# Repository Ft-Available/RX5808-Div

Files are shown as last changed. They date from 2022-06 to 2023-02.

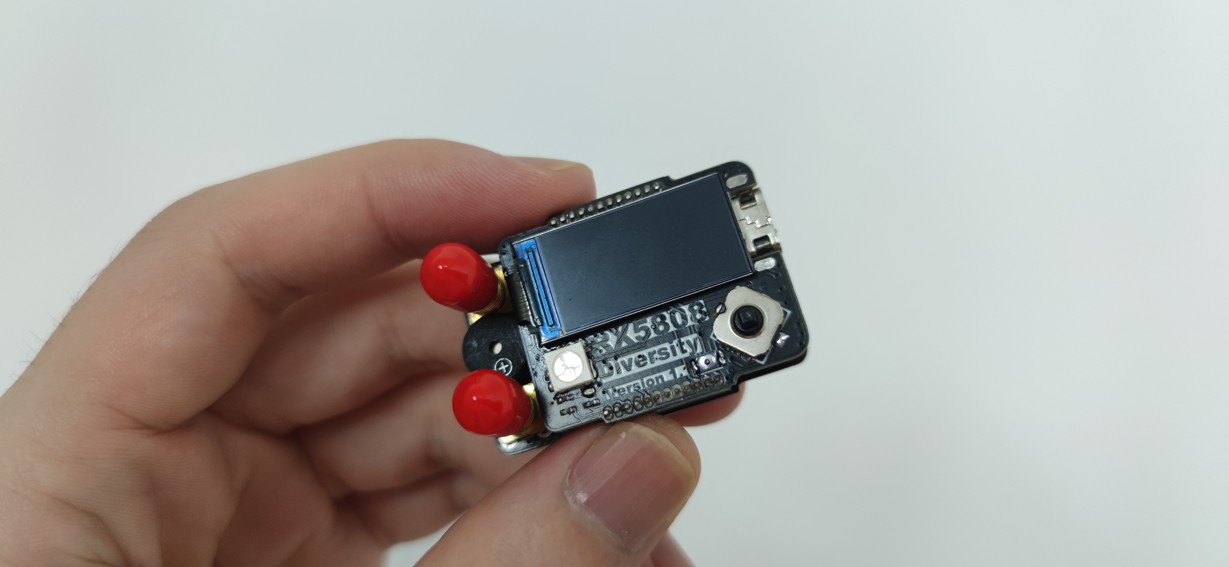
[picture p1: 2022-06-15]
Img/img3.jpg

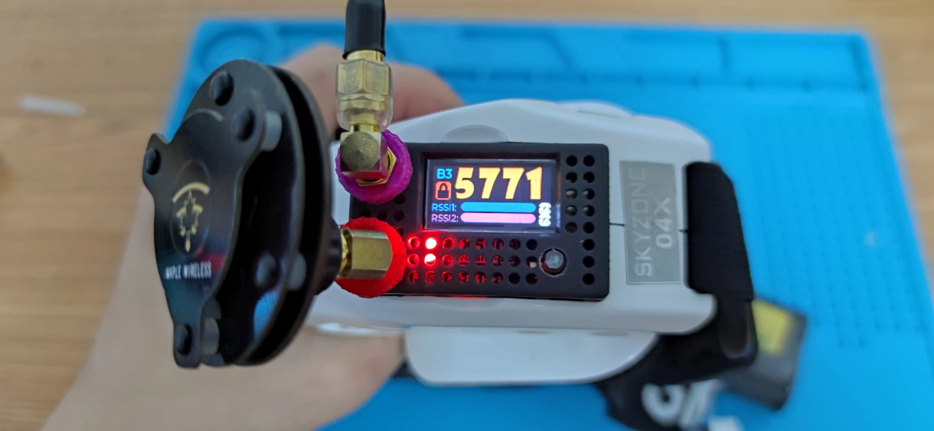
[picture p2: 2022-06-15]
Img/Skyzone_04x.jpg

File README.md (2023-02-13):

# RX5808-Div
## 1.界面设计基于LVGL

演示视频见：https://www.bilibili.com/video/BV1yr4y1371b

ui

1)主界面长按确定键，可锁定/解锁手动频道,短按进入菜单；  解锁情况下，按上下左右可调整频率。

2)菜单界面分为三块内容：扫描；设置；关于。

 按上下切换菜单选项，确定进入子菜单，左键返回主界面

3）扫描菜单有三个子内容：

图扫描显示频率5300-5900MHz信号强度；

表扫描显示将图传频道信号强度按不同颜色显示，扫描结束，频率切换至最当前信号强度最好的频道，并显示在右上角。

RSSI校准用于校准RSSI,未开启图传会校准失败，成功则会保存结果。

4）设置界面可设置显示屏背光强度，风扇转速、开机动画、蜂鸣器等是否开启，OSD制式需要保存后重新在主页面开启才能生效。

5）关于界面显示相关信息。

## 2.OSD支持

OSD功能由林面包（B站ID）添加，非叠加模式，主界面下解锁即可开启。

演示视频见：[https://www.bilibili.com/video/BV1ya411g78U ](https://www.bilibili.com/video/BV1ya411g78U) 与接收机UI完全同步。

osd

## 3.硬件设计

硬件开源地址：https://oshwhub.com/ftps/rx5808-div

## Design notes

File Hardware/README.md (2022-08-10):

# RX5808-Div-Hardware
Top 文件夹下为控制电路硬件源工程（AD）

-----ESP32         （ESP32版本带串口和USB）

    

-----ESP32_Model         （ESP32模组版本  无串口和USB）

    

因个人时间原因，交由网友打样，暂未发现问题，固件和ESP32版本不一致，详细请看TOOl文件夹下说明

-----STM32         （SMT32版本）

   

BUT 文件夹下为双RX5808接收电路硬件源工程（AD）



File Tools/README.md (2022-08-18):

# RX5808-Div-Tool

RX5808下载固件指南

一、	STM32版本

STM32固件为STM32_Firmware.zip，STM32可用USB，UART，SWD下载，不再赘述。

二、	ESP32版本

1、解压此目录下ESP32_FirmWare.zip文件夹，得到三个xxx.bin文件，如下图：



2、解压此目录下flash_download_tool_3.9.2_0.zip文件夹，得到以下文件：


 
3、双击flash_download_tool_3.9.2_0.exe打开下载程序：



选择ESP32并点击OK。

4.将解压得到的bin文件按下图顺序打开：

         bootloader.bin     0x1000
         
         partition-table.bin  0x8000
         
         RX5808.bin        0x10000 
         
 

5.SPIFLASH按下图设置：


 
6.选择COM口并下载：（下图是下载完成的样子）
 


7.问题
如遇花屏问题用ESP32_FirmWare_Slow固件。

2022.8.10新增模组版固件为ESP32_Model_FirmWare。

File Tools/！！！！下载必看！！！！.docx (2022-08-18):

RX5808下载固件指南

给我小板凳儿

1、 STM32版本

STM32固件为STM32_Firmware.zip

STM32可用USB，UART，SWD下载，不再赘述。

2、 ESP32版本

1、解压此目录下ESP32_FirmWare.zip文件夹，得到三个xxx.bin文件，如下图：

2、解压此目录下flash_download_tool_3.9.2_0.zip文件夹，得到以下文件：

3、双击flash_download_tool_3.9.2_0.exe打开下载程序：

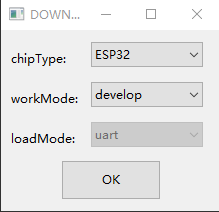
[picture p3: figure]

选择ESP32并点击OK。

4.将解压得到的bin文件按下图顺序打开：

bootloader.bin 0x1000

partition-table.bin 0x8000

RX5808.bin 0x10000

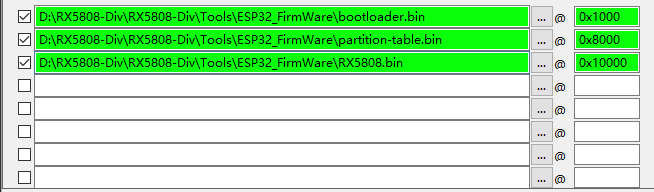
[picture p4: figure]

5.SPIFLASH按下图设置：

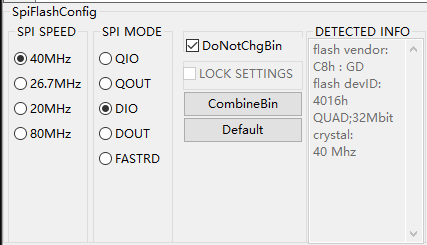
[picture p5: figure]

6.选择COM口并下载：（下图是下载完成的样子）

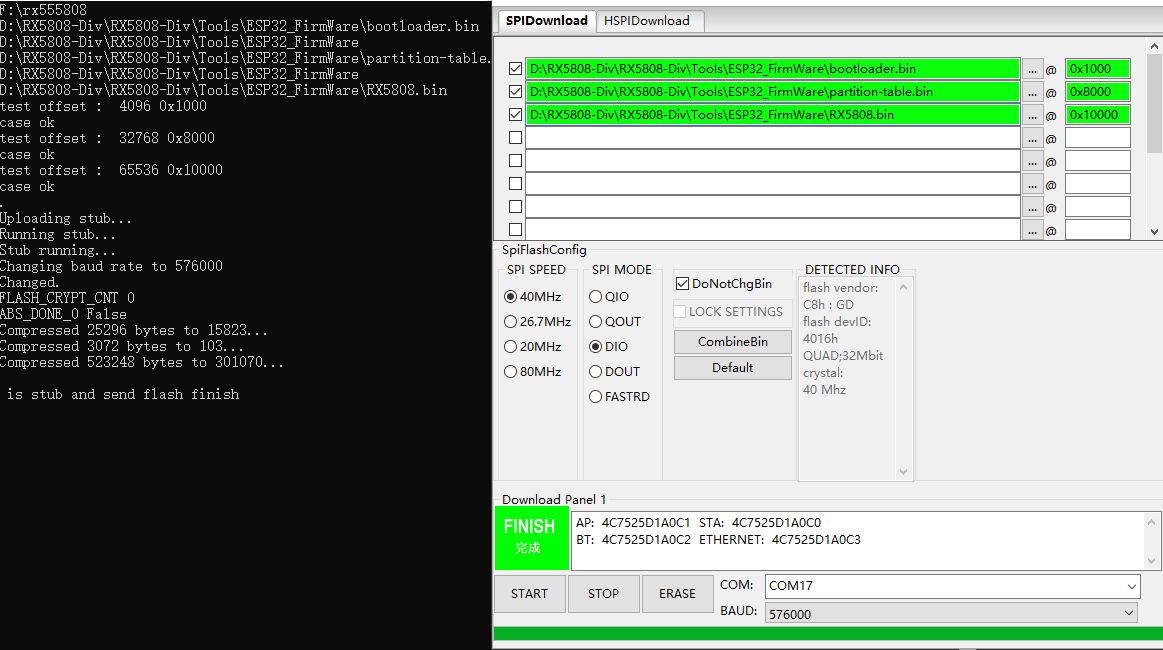
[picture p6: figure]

7.问题

如遇花屏问题用ESP32_FirmWare_Slow固件。

模组版固件为ESP32_Model_FirmWare。

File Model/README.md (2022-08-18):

# RX5808-Div-Model

Skyzone_04x文件夹下适用于Skyzone_04系列眼镜：

提供源文件和打印文件，大家可自行更改

Skyzone_04x_Model

Fatshark_Hdo文件夹下模型由网友(B站 DP团队)贡献：

材料 ：光固化和尼龙烧结（耐温高于65度）， PLA PETG 等材料都可以

FDM打印机在打印过程中不需要开启支撑，层高0.1 ，喷嘴直径不能大于0.4mm

风扇版本为1504 风扇

 



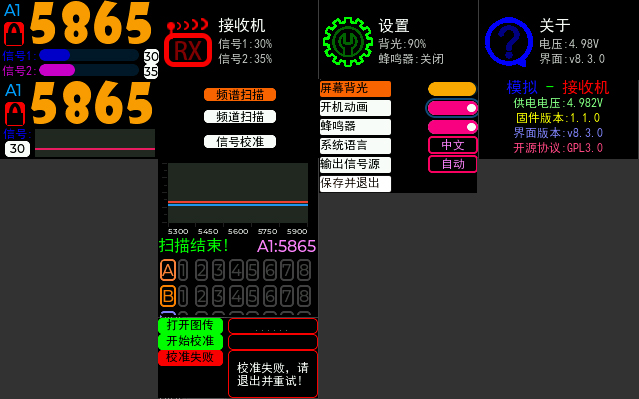
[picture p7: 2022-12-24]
Img/ui.jpeg

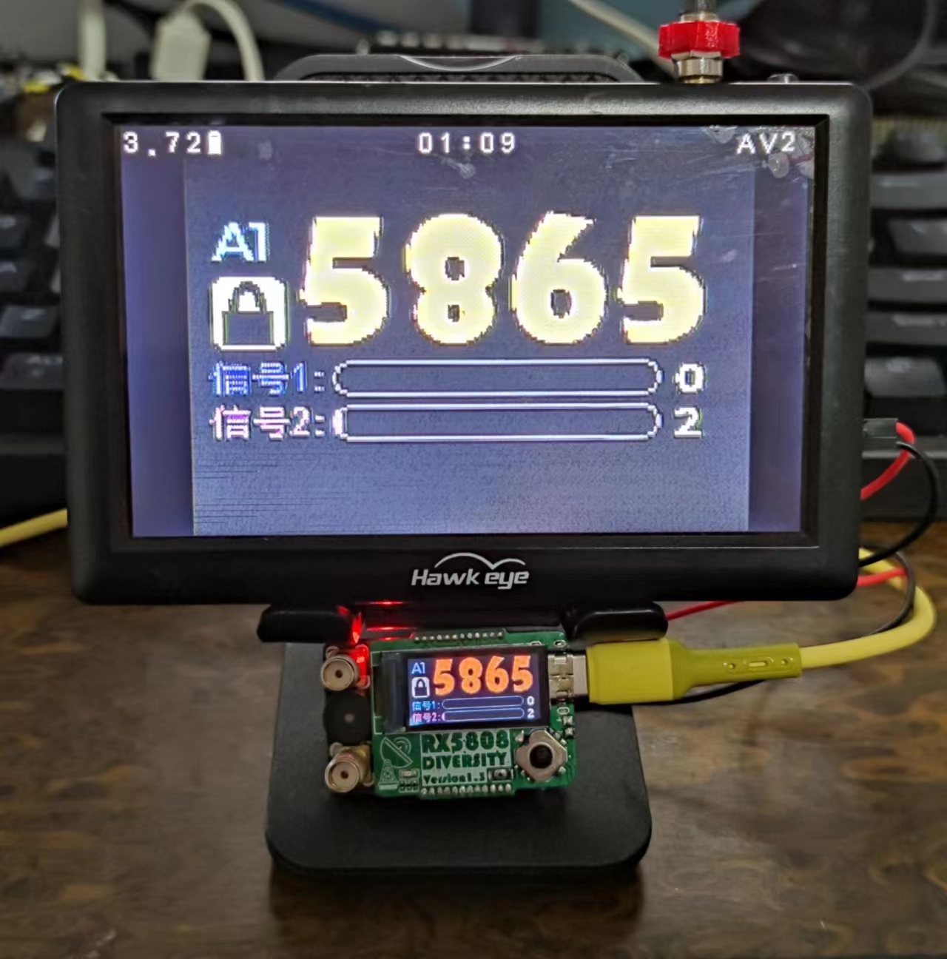
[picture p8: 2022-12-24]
Img/osd.jpeg

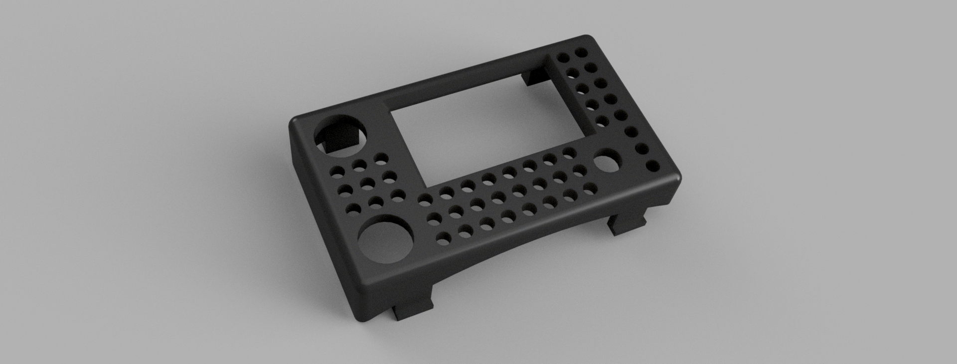
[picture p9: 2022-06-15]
Img/Skyzone_04x_Model.png

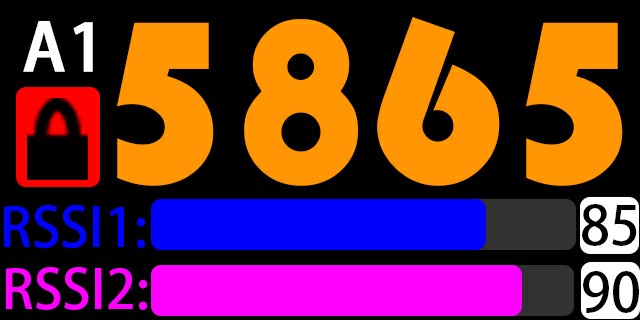
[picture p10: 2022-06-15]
Resources/main.jpg

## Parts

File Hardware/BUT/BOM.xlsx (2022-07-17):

Comment | Description | Designator | Footprint | LibRef | Quantity
BELL | 有源蜂鸣器 | BEEP1 | BEEP 5x9x5.5 | Beep | 1
RX5808 | SPI控制RX5808 | CM1, CM2 | COMM-SMD_12P_RX5808 | RX5808 | 2
LED | LED | DS1 | 0402_LED | LED | 1
Header 9 | Header, 9-Pin | P1 | HDR-1X9 | Header 9 | 1
Header 12 | Header, 12-Pin | P2, P3 | HDR1.27-1x12-M | Header 12 | 2
SS8050 | NPN三极管 | Q1 | SOT23A | SS8050 | 1
1K | 电阻 | R1, R3 | 0402_RES | RES | 2
10K | 电阻 | R2 | 0402_RES | RES | 1
SMA-KE901 | >17mm天线座 | RF1, RF2 | SMA-TH_SMA-KE901 | SMA-KE901 | 2

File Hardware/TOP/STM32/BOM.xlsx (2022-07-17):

Comment | Description | Designator | Footprint | LibRef | Quantity
100nf | 无极性电容 | C1, C4, C5, C6, C7, C8, C9, C10, C11, C12, C13, C14, C15, C16, C17 | 0402_CAP | Cap | 15
47uf | 极性电解电容 | C2 | CAP-3216 | Cap Pol | 1
10uf | 无极性电容 | C3 | 1206_CAP | Cap | 1
RGB LED | 无极性电容 | D1 | LED-SMD_6P-L5.0-W5.0-TL | WS2812 | 1
LED | LED | DS1 | 0402_LED | LED | 1
USB type C | TYPEC接口-16PIN | J1 | USB-C-SMD_TYPE-C-16M-005 | Type-C | 1
2.2uH | 电感 | L1 | L 1206 | Inductance | 1
Header 12 | 排针 | P1, P2 | HDR1.27-1x12 | Header 12 | 2
SS8050 | NPN三极管 | Q1 | SOT23A | SS8050 | 1
100K | 电阻 | R1 | 0402_RES | RES | 1
22K | 电阻 | R2, R6 | 0402_RES | RES | 2
22R | 电阻 | R3, R4 | 0402_RES | RES | 2
1M | 电阻 | R5, R7 | 0402_RES | RES | 2
10R | 电阻 | R8 | 0402_RES | RES | 1
1K | 电阻 | R9, R15 | 0402_RES | RES | 2
10K | 电阻 | R10, R11, R12, R13, R14, R16, R17 | 0402_RES | RES | 7
薄膜按键 | 薄膜按键 | REST1 | SW-SMD_ST-1195 | Jumper | 1
7*7*5-6P WX | 五向按键 | SW1 | SW-SMD_8P-L7.0-W7.0-P1.40-LS7.4-TL | 7*7*5-6P WX | 1
IPS0.96_80x160 | IPS-80x160 | TFT1 | IPS-0.96 | IPS0.96_80x160 | 1
SY8079AAC | DCDC电源 | U1 | SOT-23-5_L3.0-W1.7-P0.95-LS2.8-TL | SY8079AAC | 1
74LVC4066PW | 模拟开关 | U2 | SSOP-14_L6.5-W5.2-P0.65-LS8.0-BL | 74LVC4066PW | 1
STM32F411CEU6 | STM32单片机 | U3 | UFQFPN-48_L7.0-W7.0-P0.50-BL-EP | STM32F411CEU6 | 1
ZD24C64A-XGMT | E2PROM | U4 | TSSOP-8_L4.4-W3.0-P0.65-LS6.4-BL-2 | ZD24C64A-XGMT | 1
8M | 晶振 | Y1 | CSTCE8M00G55 | XTAL_1 | 1

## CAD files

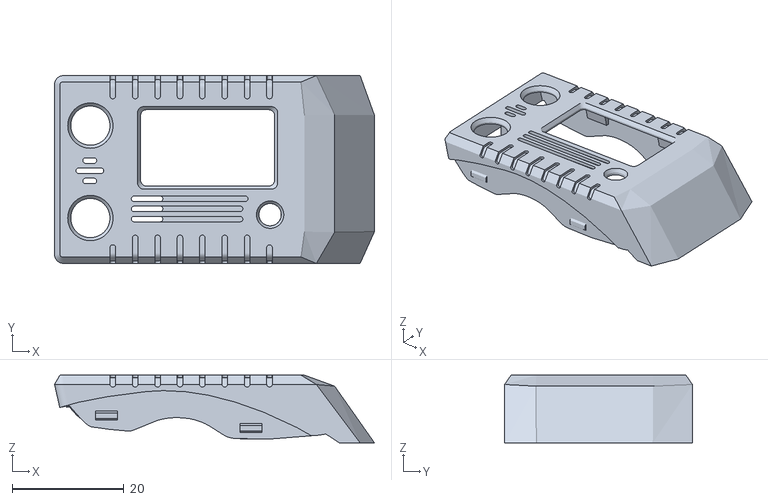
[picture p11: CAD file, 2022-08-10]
Model/Fatshark_Hdo/FatShark5808.stl
57.2 x 33.6 x 12.1

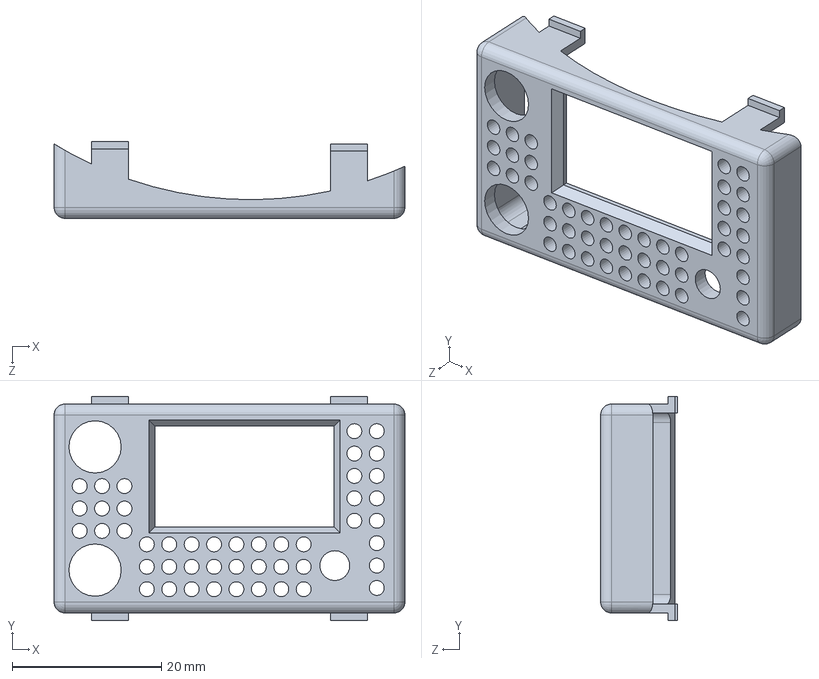
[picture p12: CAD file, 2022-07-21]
Model/Skyzone_04x/Skyzone_04x.SLDPRT
47.0 x 30.0 x 10.3 mm

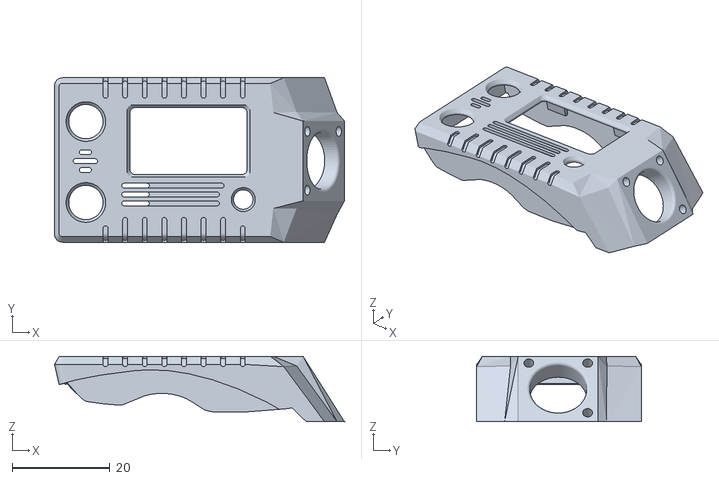
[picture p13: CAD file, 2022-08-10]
Model/Fatshark_Hdo/FatShark5808_1504.stl
59.2 x 33.6 x 13.4

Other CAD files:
Model/Skyzone_04x/Skyzone_04x.STL

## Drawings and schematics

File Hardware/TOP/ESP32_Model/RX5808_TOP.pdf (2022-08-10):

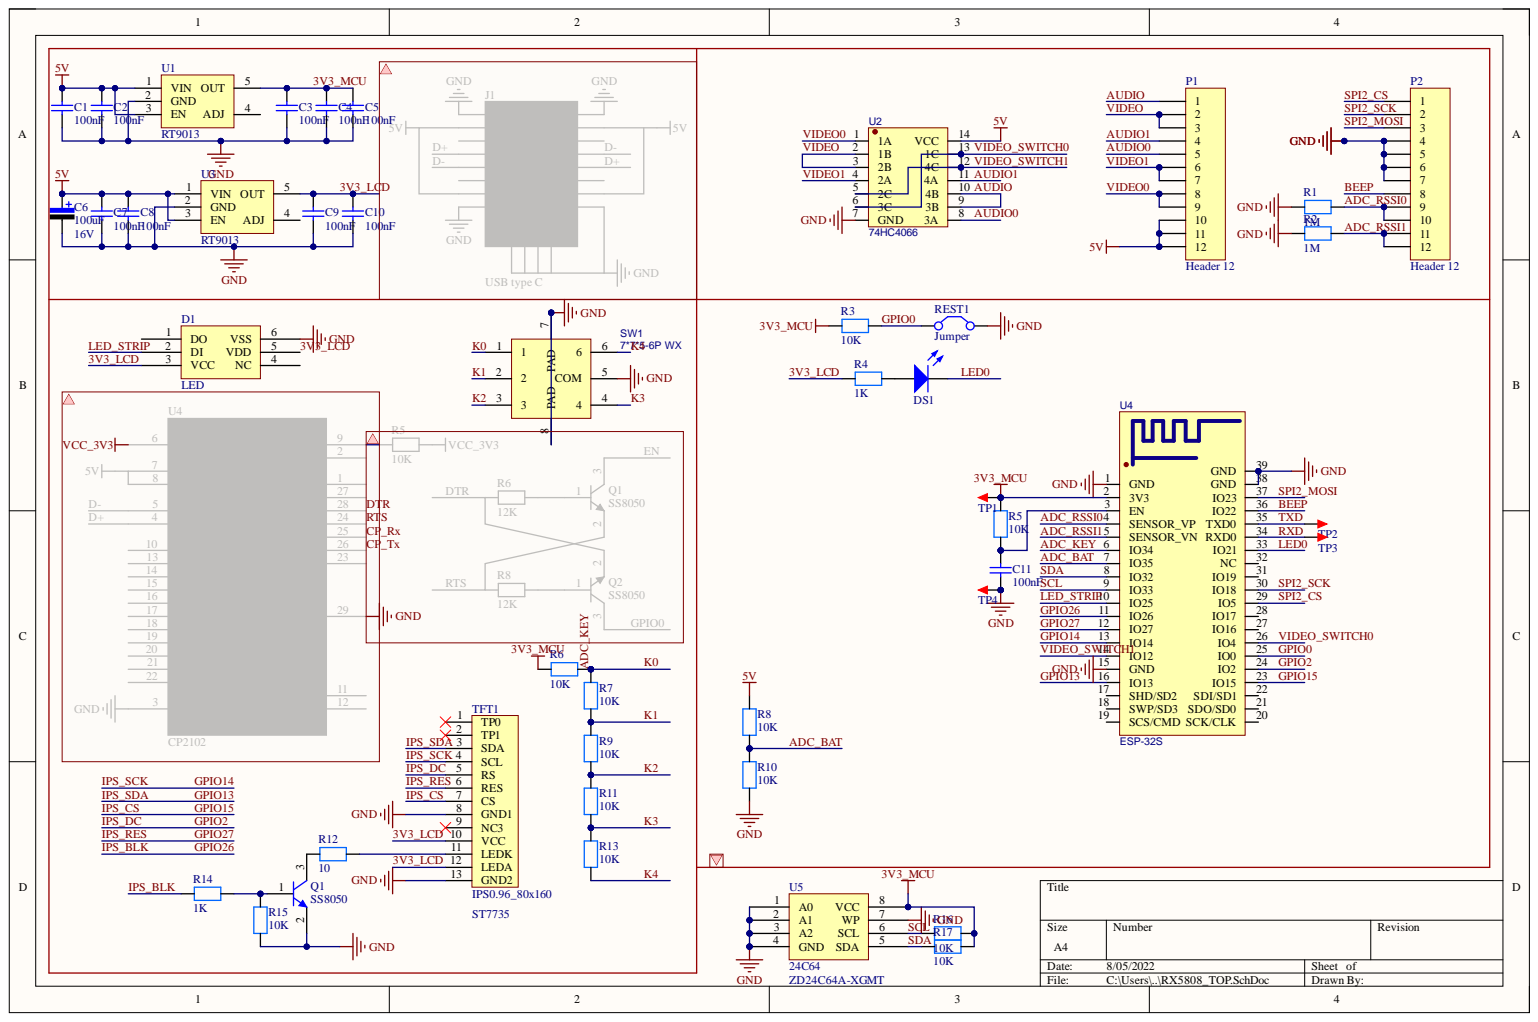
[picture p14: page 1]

GND 4 | SDA

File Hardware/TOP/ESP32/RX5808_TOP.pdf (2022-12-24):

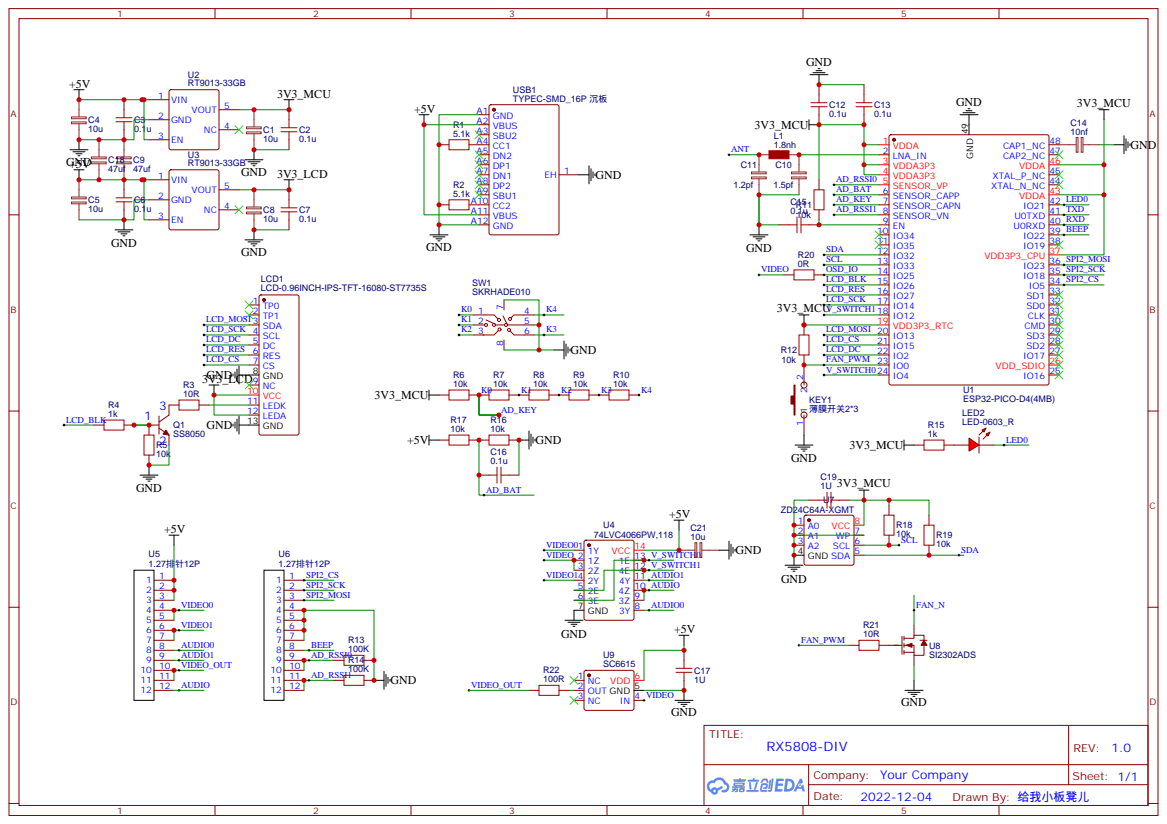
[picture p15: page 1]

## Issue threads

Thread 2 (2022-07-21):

Shell model for fatshark HDO

luttesudo, 2022-07-21:
Do you have a case model for the fatshark HDO? Or is there a modifiable file for O4X?

Ft-Available, 2022-07-21:
I don't have fat shark glasses, so I didn't design the 3D model, now I have uploaded the 04X modifiable model, which was designed with SolidWords.

luttesudo, 2022-07-21:
Thank you for the upload, I will share the model after I revise it, it may be later, I am more busy

Closed 2023-09-29.

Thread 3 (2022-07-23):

看到esp32修改了几个电容，请问这个改动的是否重要

Mason-star, 2022-07-23:

Ft-Available, 2022-07-23:
不知道你说的是哪几个电容，和esp相连的C11 10nf不可更改更不可缺少，其次esp32 天线Π型电路的电容和电感不可更改，其余电容大都为滤波作用，可以适当更改和替换。

Mason-star, 2022-07-23:
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

之前一个版本，bom表除了c11以外都为100nf，这两天，仔细看了一下原理图，发现c15和c16是1.2pf和1.5pf，c10为100nf和bom表有些出入，是pcb改动导致的bom表变动，还是bom表有误？

Ft-Available, 2022-07-23:
BOM表有误，已修改并上传，主要参考原理图

Closed 2022-07-23.

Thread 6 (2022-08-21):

OSD支持 - OSD Support Request

ChisBread, 2022-08-21:
hello, 这里是刚接触嵌入式几天的新手(计算机专业,目前是后端开发)，说的不对还请多多包涵

**功能描述:**
参考RF接收机提供的使用接收屏调参的OSD功能，在调整频段时无需摘下眼镜
**ESP32 A/V输出:**
我研究了一下esp32通过DAC实现A/V输出的可行性，似乎效果相当不错
《ESP32 Composite Video(ESP32 合成视频)》
https://www.youtube.com/watch?v=5t1_XNc3vNw
https://www.bilibili.com/video/BV12V411o7xW
**改造项目的可能性:**
TOP:
我阅读了固件代码和原理图，DAC引脚目前被IPS_BLK和LED_STRIP占用了，可能需要另想办法。不清楚74HC4066是否能加一路video输入，按我的理解应该是不够用了（4路的输入被a0,a1,v0,v1占了, 如果用6路的开关也许可以实现这个功能?)
BUT:
好像不需要做什么改动

最后感谢作者的开源，让我有一个非常有趣的入门体验！没有什么比学习新东西更快乐的了 :D

ChisBread, 2022-08-22:
Supports [LVGL](https://lvgl.io/) graphics library
https://github.com/aquaticus/esp32_composite_video_lib

ChisBread, 2022-08-29:
https://github.com/ChisBread/RX5808-Div/tree/composite_video
我自己写了
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

Ft-Available, 2022-08-29:
这个很有意思，你已经实现了，(●'◡'●)。

ChisBread, 2022-08-29:
是啊，不知道你在不在蛋总（独自飞舞）的群里
我写好固件，修改了原理图（去掉了RGB，加上了双刀单掷模拟开关），蛋总帮我修改了PCB然后去打样了
长按解锁后，VIDEO切换到DAC_VIDEO，这样眼镜里就能看到OSD UI
因为和主线代码相差比较多，硬件也不一样，所以单开了分支，希望之后这个功能可以合并到主线

caixiaohai0, 2022-08-29:
> 是啊，不知道你在不在蛋总（独自飞舞）的群里 我写好固件，修改了原理图（去掉了RGB，加上了双刀单掷模拟开关），蛋总帮我修改了PCB然后去打样了 长按解锁后，VIDEO切换到DAC_VIDEO，这样眼镜里就能看到OSD UI 因为和主线代码相差比较多，硬件也不一样，所以单开了分支，希望之后这个功能可以合并到主线

大佬，可以上传原理图到你的分支里？

ChisBread, 2022-08-29:
> > 是啊，不知道你在不在蛋总（独自飞舞）的群里 我写好固件，修改了原理图（去掉了RGB，加上了双刀单掷模拟开关），蛋总帮我修改了PCB然后去打样了 长按解锁后，VIDEO切换到DAC_VIDEO，这样眼镜里就能看到OSD UI 因为和主线代码相差比较多，硬件也不一样，所以单开了分支，希望之后这个功能可以合并到主线
>
> 大佬，可以上传原理图到你的分支里？

我用macOS不能直接修改作者的工程文件（需要转成其它格式），所以没办法可协作地改动repo里的原理图
出于可维护性考虑，这部分的希望还是作者来统一修改
这是我的原理图，圈起来的是修改的部分(待勘误)，如果作者同步完，验证无误的话。可以在我的[composite_video](https://github.com/ChisBread/RX5808-Div/tree/composite_video)分支合并后提交到主线。
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

这个DAC VIDEO也许不仅可以作为OSD，别的玩法可以在合并后研究研究

ChisBread, 2022-08-29:
video功能合并前，先打开这个issue吧

ChisBread, 2022-08-29:
这个原理图图中有一处不规范，type-c的CC1 CC2应该分别接下拉电阻

caixiaohai0, 2022-08-30:
大佬，你原理图部分是按照那个模块或芯片画的，我对比了一下esp32 wroom-32d这个模块的原理图发现闪存这部分IO和你的不一样
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

caixiaohai0, 2022-08-30:
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

大佬，你原理图部分是按照那个模块或芯片画的，我对比了一下esp32 wroom-32d这个模块的原理图发现闪存这部分IO和你的不一样
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

ChisBread, 2022-08-30:
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

原项目是ESP32 Pico D4 (不是大佬，真的才学两周)

caixiaohai0, 2022-08-30:
> ESP32 Pico D4

可以考虑分支个esp32 wroom-32d模块固件吗？找了一圈没找到哪个是io定义的，还是技术不到家，23333

ChisBread, 2022-08-30:
> > ESP32 Pico D4
>
> 可以考虑分支个esp32 wroom-32d模块固件吗？找了一圈没找到哪个是io定义的，还是技术不到家，23333

和主题无关的内容请另提issue

ChisBread, 2022-08-30:
@Ft-Available https://github.com/ChisBread/DawnOfAV
似乎彩色视频也是可以合成的，我在尝试移植

ChisBread, 2022-09-06:
hello 我已经实现了稳定的彩色输出，并提交了PR
演示视频:
https://www.bilibili.com/video/BV1kD4y1B7WB

ChisBread, 2022-11-11:
已解决，见:
https://github.com/Ft-Available/RX5808-Div/pull/12

Closed 2022-11-11.

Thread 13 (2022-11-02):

请问，你的LVGL是用什么工具设计的UI吗？还有那个切换有弹性的效果

zouzhe1, 2022-11-02:

Ft-Available, 2022-11-10:
lvgl就是一个UI框架，界面是基于这个框架做的，弹性的效果是lvgl自带的，有许多效果，线性，弹性，窗帘式等。。。。

zouzhe1, 2022-11-11:
@Ft-Available 我用过LVGL。所以我问的是你用的什么软件，弄LVGL。比如nxp的guider。还有lvgl自己也出了一个收费的软件。因为我觉得你画的这个很好。我自己弄的特差。

Ft-Available, 2022-11-11:
借助了PhotoShop，把界面画出来，然后用仓库里面的Visual Studio模拟器设计，跑一下，LVGL官方的一些工具我自己没有用过，但是用这些工具应该会更便捷，只不过需要学习一下。

Closed 2023-09-29.

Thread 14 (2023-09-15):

大佬，请问海星D1的刷了咱这个固件后五维按键不好使了，想加点东西求帮助

sharkor, 2023-09-15:
我想在接收机上学习一下esp32的开发，自己加点功能开发试试，现在手头用的是贝壳的海星D1，刷了咱的固件后五维按键失效，问了客服，说是您给开发的，特来求教，是否可以把贝壳D1的源代码分享一下，非常感谢

Ft-Available, 2023-09-15:
按键ad分压的电阻值他们好像改过，具体多少并不清楚，可以打开按键分压采样的打印，然后修改一下即可
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

sharkor, 2023-09-16:
非常感谢，帮了大忙了

sharkor, 2023-09-16:
> 按键修改广告分压的抵抗值他们希望改过，具体多少并穆斯林，可以打开按键分压采样的打印，然后一下就可以了 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

不好意还得继续打扰一下，还是出了点问题，我这里打印的值是0，我怀疑他们使用的是不同的ADC引脚。

sharkor, 2023-09-16:
> 按键ad分压的电阻值他们好像改过，具体多少并不清楚，可以打开按键分压采样的打印，然后修改一下即可 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

不好意还得继续打扰一下，还是出了点问题，我这里打印的值是0，我怀疑他们使用的是不同的ADC引脚。

Ft-Available, 2023-09-16:
hwver.h里面切一下模组版的，如果不行那就是他们改过了

sharkor, 2023-09-16:
> hwver.h里面切一下模组版的，如果不行那就是他们改过了

好的谢谢啦，我试试实在不行就重新个主控板了

sharkor, 2023-09-16:
> hwver.h里面切一下模组版的，如果不行那就是他们改过了

再次感谢，切换了模组后直接可以了，阻值也是不用改的

Closed 2023-09-16.

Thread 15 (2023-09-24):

Chip CPU frequency rated for 160MHz, configured for 240MHz. Modify CPU frequency in menucog

NorthWardTop, 2023-09-24:
小板凳您好,
我想飞线加上OSD功能, 按照林面包的方法短接上侧排针倒数第二第三个, 并引至彩色LED灯右下引脚
尝试烧录你的固件后, 出现如标题所示错误一直重启, 我也使用的是esp32 pico D4理论是是240Hz芯片才对
我尝试clone你的仓库, 自行编译, 出现编译错误:RX5808-Div/Firmware/ESP32/RX5808/main/gui/lvgl_driver/lv_port_disp.c:15:10: fatal error: capi_video.h: No such file or directory
我是使用的是最新的esp_idf v5.2版本

我想请教如下问题:
1.capi_video.h是esp_idf的库还是第三方库, 要如何获取这个库, 解决这个编译错误
2.你通常使用哪个esp_idf版本编译
3.我的飞线方法是否正确
4.您是否了解esp32 pico D4有160MHz的主频型号, 如果我的是160MHz主频是否sdkconfig修改CPU频率即可

期待您的回复, 感激不尽!

附开机错误日志如下:
rst:0x3 (SW_RESET),boot:0x13 (SPI_FAST_FLASH_BOOT)
configsip: 188777542, SPIWP:0xee
clk_drv:0x00,q_drv:0x00,d_drv:0x00,cs0_drv:0x00,hd_drv:0x00,wp_drv:0x00
mode:DIO, clock div:1
load:0x3fff0030,len:7320
load:0x40078000,len:14976
load:0x40080400,len:3688
entry 0x4008067c
E (58) boot.esp32: Chip CPU frequency rated for 160MHz, configured for 240MHz. Modify CPU frequency in menucog
ets Jun  8 2016 00:22�ets Jun  8 2016 00:22:57

Ft-Available, 2023-09-24:
1.git clone 后 git submodule update --init --recursive ，或者进入chisbread仓库下载替换即可
2.esp-idf4.0
3.正确，建议看我立创开源的飞线方法
4 espidf支持配置esp32主频80M 160M 240M，并没有还根据频率分型号的，编译通过下载应该就可以了。
5.可以立创或者b站找我。

Closed 2023-09-29.

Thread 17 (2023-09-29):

BAYCK Starfish D1 Support

lesharodin, 2023-09-29:
Sorry I closed https://github.com/Ft-Available/RX5808-Div/issues/16 too early
Seems like there is some design difference?
On 1.4 fw - video works, but keypad doesnt
On 1.3 ( ESP32_Firmware_Simple ) fw - no video, but keypad works.
What is the difference was made to keypad from 1.3 to 1.4?

lesharodin, 2023-09-29:
Why on 1.4 joystick not working?

lesharodin, 2023-10-01:
[starfishD1_backup.zip](https://github.com/Ft-Available/RX5808-Div/files/12776752/starfishD1_backup.zip)
If anyone interested, there is a factory dump of starfish flash.
write at 0x0

Ft-Available, 2023-10-02:
Hello! There are two versions of hardware, chip board and module board. The pins connected to the keyboard in these two versions are not the same. In 1.4, I only uploaded the chip version, which resulted in the keyboard not working.

Ft-Available, 2023-10-02:
Now I have uploaded another firmware version, you can try it out!

lesharodin, 2023-10-03:
> Now I have uploaded another firmware version, you can try it out!

Thanks will try, how to build different version?

Ft-Available, 2023-10-05:
Just modify the macro definition in hwvers. h

lesharodin, 2023-10-05:
This segment?
```

#ifndef D0WDQ6_VER
#define VBAT_ADC_CHAN      ADC1_CHANNEL_1
#define KEY_ADC_CHAN       ADC1_CHANNEL_2
#else
#define VBAT_ADC_CHAN      ADC1_CHANNEL_7
#define KEY_ADC_CHAN       ADC1_CHANNEL_6

```

Ft-Available, 2023-10-05:
yes

lesharodin, 2023-10-09:
Thanks, [this  versio](https://github.com/Ft-Available/RX5808-Div/releases/download/1.4.0/ESP32_Model.zip)
This firmware works

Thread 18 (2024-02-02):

elrs backpack supoort

arthurson, 2024-02-02:
it seems the latest firware do not support elrs backpack function at the moment, will the hardware itself support it after the new firmware release?

Dmarkovskyi, 2024-09-15:
Maybe exist some easy way to enable elrs backpack support ?

FanSails, 2025-01-01:
同求支持ELRS调参

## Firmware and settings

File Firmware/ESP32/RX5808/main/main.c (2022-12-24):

#include <stdio.h>
#include "sdkconfig.h"
#include "freertos/FreeRTOS.h"
#include "freertos/task.h"
#include "esp_system.h"
#include "esp_spi_flash.h"
#include "system.h"
#include "lvgl_init.h"

void app_main(void)
{

    system_init();
    lvgl_init();
    while(1){
    lv_task_handler();
    vTaskDelay(10 / portTICK_PERIOD_MS);
    }
}

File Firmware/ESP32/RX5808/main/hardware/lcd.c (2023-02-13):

#include "lcd.h"
#include "SPI.h"
#include "freertos/task.h"
#include <string.h>
#include "driver/mcpwm.h"
#include "soc/mcpwm_reg.h"
#include "soc/mcpwm_struct.h"
#include "../../lvgl.h"
#include "hwvers.h"


#define st7735_lcd_backlight_min 10
#define st7735_lcd_backlight_max 100

volatile uint8_t st7735_lcd_backlight=100;


inline void LCD_Writ_Bus(uint8_t dat) 
{	

    esp_err_t ret;
    spi_transaction_t t;
    memset(&t, 0, sizeof(t));       //Zero out the transaction
    t.length=8;                     //Command is 8 bits
    t.tx_buffer=&dat;               //The data is the cmd itself
    //t.user=(void*)1;                //D/C needs to be set to 0
    ret=spi_device_polling_transmit(my_spi, &t);  //Transmit!
    assert(ret==ESP_OK);            //Should have had no issues.

}

void LCD_WR_DATA8(uint8_t da) 
{ 
   LCD_Writ_Bus(da);
}  
void LCD_WR_DATA(uint16_t dat)
{
    LCD_Writ_Bus(dat>>8);
	LCD_Writ_Bus(dat);

}   

void LCD_WR_REG(uint8_t da)   
{ 
	gpio_set_level(PIN_NUM_DC, 0);
	LCD_Writ_Bus(da);
	gpio_set_level(PIN_NUM_DC, 1);
}


void Address_Set(uint16_t x1,uint16_t y1,uint16_t x2,uint16_t y2)
{ 
#ifndef ST7735S
    if(USE_HORIZONTAL==0)
	{
		LCD_WR_REG(0x2a);//列地址设置
		LCD_WR_DATA(x1+26);
		LCD_WR_DATA(x2+26);
		LCD_WR_REG(0x2b);//行地址设置
		LCD_WR_DATA(y1+1);
		LCD_WR_DATA(y2+1);
		LCD_WR_REG(0x2c);//储存器写
	}
	else if(USE_HORIZONTAL==1)
	{
		LCD_WR_REG(0x2a);//列地址设置
		LCD_WR_DATA(x1+26);
		LCD_WR_DATA(x2+26);
		LCD_WR_REG(0x2b);//行地址设置
		LCD_WR_DATA(y1+1);
		LCD_WR_DATA(y2+1);
		LCD_WR_REG(0x2c);//储存器写
	}
	else if(USE_HORIZONTAL==2)
	{
		LCD_WR_REG(0x2a);//列地址设置
		LCD_WR_DATA(x1+1);
		LCD_WR_DATA(x2+1);
		LCD_WR_REG(0x2b);//行地址设置
		LCD_WR_DATA(y1+26);
		LCD_WR_DATA(y2+26);
		LCD_WR_REG(0x2c);//储存器写
	}
	else
	{
		LCD_WR_REG(0x2a);//列地址设置
		LCD_WR_DATA(x1+1);
		LCD_WR_DATA(x2+1);
		LCD_WR_REG(0x2b);//行地址设置
		LCD_WR_DATA(y1+26);
		LCD_WR_DATA(y2+26);
		LCD_WR_REG(0x2c);//储存器写
	}
#else
    if(USE_HORIZONTAL==0)
	{
		LCD_WR_REG(0x2a);//列地址设置
		LCD_WR_DATA(x1+24);
		LCD_WR_DATA(x2+24);
		LCD_WR_REG(0x2b);//行地址设置
		LCD_WR_DATA(y1);
		LCD_WR_DATA(y2);
		LCD_WR_REG(0x2c);//储存器写
	}
	else if(USE_HORIZONTAL==1)
	{
		LCD_WR_REG(0x2a);//列地址设置
		LCD_WR_DATA(x1+24);
		LCD_WR_DATA(x2+24);
		LCD_WR_REG(0x2b);//行地址设置
		LCD_WR_DATA(y1);
		LCD_WR_DATA(y2);
		LCD_WR_REG(0x2c);//储存器写
	}
	else if(USE_HORIZONTAL==2)
	{
		LCD_WR_REG(0x2a);//列地址设置
		LCD_WR_DATA(x1);
		LCD_WR_DATA(x2);
		LCD_WR_REG(0x2b);//行地址设置
		LCD_WR_DATA(y1+24);
		LCD_WR_DATA(y2+24);
		LCD_WR_REG(0x2c);//储存器写
	}
	else
	{
		LCD_WR_REG(0x2a);//列地址设置
		LCD_WR_DATA(x1);
		LCD_WR_DATA(x2);
		LCD_WR_REG(0x2b);//行地址设置
		LCD_WR_DATA(y1+24);
		LCD_WR_DATA(y2+24);
		LCD_WR_REG(0x2c);//储存器写
	}
#endif
	
}



void pwm_init()
{
	mcpwm_pin_config_t pin_config = {
		.mcpwm0a_out_num = -1,
		.mcpwm0b_out_num = PIN_NUM_BCKL
	};
	mcpwm_set_pin(MCPWM_UNIT_0, &pin_config);
	mcpwm_config_t pwm_config;
	pwm_config.frequency = 10000;    //frequency = 1000Hz
	pwm_config.cmpr_a = 0.0;       //duty cycle of PWMxA = 60.0%
	pwm_config.cmpr_b = 0.0;       //duty cycle of PWMxb = 50.0%
	pwm_config.counter_mode = MCPWM_UP_COUNTER;
	pwm_config.duty_mode = MCPWM_DUTY_MODE_0;
	mcpwm_init(MCPWM_UNIT_0, MCPWM_TIMER_0, &pwm_config);   //Configure PWM0A & PWM0B with above settings

  //mcpwm_set_duty(MCPWM_UNIT_0, MCPWM_TIMER_0, 0, 100);
  mcpwm_set_duty(MCPWM_UNIT_0, MCPWM_TIMER_0, 1, 0.0);
}
   

void LCD_Init(void)
{
  
    spi_init();
    gpio_set_direction(PIN_NUM_DC, GPIO_MODE_OUTPUT);
    gpio_set_direction(PIN_NUM_RST, GPIO_MODE_OUTPUT);
    //gpio_set_direction(PIN_NUM_BCKL, GPIO_MODE_OUTPUT);
	gpio_set_level(PIN_NUM_DC, 1);
	gpio_set_level(PIN_NUM_RST, 1);
	//gpio_set_level(PIN_NUM_BCKL, 0);
    pwm_init();
	
	//gpio_set_direction(SPI_NUM_CS, GPIO_MODE_OUTPUT);
    //Reset the display
    gpio_set_level(PIN_NUM_RST, 0);
    vTaskDelay(10 / portTICK_RATE_MS);
    gpio_set_level(PIN_NUM_RST, 1);
    vTaskDelay(10 / portTICK_RATE_MS);



    LCD_WR_REG(0x11);     //Sleep out
	vTaskDelay(10 / portTICK_RATE_MS);           //Delay 120ms

	LCD_WR_REG(0xB1);     //Normal mode
	LCD_WR_DATA8(0x05);   LCD_WR_DATA8(0x3C);   LCD_WR_DATA8(0x3C);   
	LCD_WR_REG(0xB2);     //Idle mode
    LCD_WR_DATA8(0x05);   LCD_WR_DATA8(0x3C);   LCD_WR_DATA8(0x3C);   
	LCD_WR_REG(0xB3);     //Partial mode
	LCD_WR_DATA8(0x05);   LCD_WR_DATA8(0x3C);   LCD_WR_DATA8(0x3C);   LCD_WR_DATA8(0x05);   LCD_WR_DATA8(0x3C);   LCD_WR_DATA8(0x3C);   
	LCD_WR_REG(0xB4);     //Dot inversion
	LCD_WR_DATA8(0x03);   
	LCD_WR_REG(0xC0);     //AVDD GVDD
	LCD_WR_DATA8(0xAB);   LCD_WR_DATA8(0x0B);   LCD_WR_DATA8(0x04);   
	LCD_WR_REG(0xC1);     //VGH VGL
	LCD_WR_DATA8(0xC5);   //C0
	LCD_WR_REG(0xC2);     //Normal Mode
	LCD_WR_DATA8(0x0D);   LCD_WR_DATA8(0x00);   
	LCD_WR_REG(0xC3);     //Idle
	LCD_WR_DATA8(0x8D);   LCD_WR_DATA8(0x6A);   
	LCD_WR_REG(0xC4);     //Partial+Full
	LCD_WR_DATA8(0x8D);   LCD_WR_DATA8(0xEE);   
	LCD_WR_REG(0xC5);     //VCOM
	LCD_WR_DATA8(0x0F);   
	LCD_WR_REG(0xE0);     //positive gamma
	LCD_WR_DATA8(0x07);   LCD_WR_DATA8(0x0E);   LCD_WR_DATA8(0x08);   LCD_WR_DATA8(0x07);   LCD_WR_DATA8(0x10);   LCD_WR_DATA8(0x07);   
	LCD_WR_DATA8(0x02);   LCD_WR_DATA8(0x07);   LCD_WR_DATA8(0x09);   LCD_WR_DATA8(0x0F);   LCD_WR_DATA8(0x25);   LCD_WR_DATA8(0x36);   
	LCD_WR_DATA8(0x00);   LCD_WR_DATA8(0x08);   LCD_WR_DATA8(0x04);   LCD_WR_DATA8(0x10);   
	LCD_WR_REG(0xE1);     //negative gamma
	LCD_WR_DATA8(0x0A);   LCD_WR_DATA8(0x0D);   LCD_WR_DATA8(0x08);   LCD_WR_DATA8(0x07);   LCD_WR_DATA8(0x0F);   LCD_WR_DATA8(0x07);   
	LCD_WR_DATA8(0x02);   LCD_WR_DATA8(0x07);   LCD_WR_DATA8(0x09);   LCD_WR_DATA8(0x0F);   LCD_WR_DATA8(0x25);   LCD_WR_DATA8(0x35);   
	LCD_WR_DATA8(0x00);   LCD_WR_DATA8(0x09);   LCD_WR_DATA8(0x04);   LCD_WR_DATA8(0x10);
		 
	LCD_WR_REG(0xFC);    
	LCD_WR_DATA8(0x80);  
		
	LCD_WR_REG(0x3A);     
	LCD_WR_DATA8(0x05);   
	LCD_WR_REG(0x36);
	if(USE_HORIZONTAL==0)LCD_WR_DATA8(0x08);
	else if(USE_HORIZONTAL==1)LCD_WR_DATA8(0xC8);
	else if(USE_HORIZONTAL==2)LCD_WR_DATA8(0x78);
	else LCD_WR_DATA8(0xA8); 
#ifndef  ST7735S
	LCD_WR_REG(0x21);     //Display inversion
#endif
	LCD_WR_REG(0x29);     //Display on
	LCD_WR_REG(0x2A);     //Set Column Address
	LCD_WR_DATA8(0x00);   LCD_WR_DATA8(0x1A);  LCD_WR_DATA8(0x00);   LCD_WR_DATA8(0x69);   
	LCD_WR_REG(0x2B);     //Set Page Address
	LCD_WR_DATA8(0x00);   LCD_WR_DATA8(0x01);    LCD_WR_DATA8(0x00);   LCD_WR_DATA8(0xA0);  
	LCD_WR_REG(0x2C);

 
	
    //LCD_Fill(0,0,160,80,BLACK);
	LCD_Clear();
	vTaskDelay(10 / portTICK_RATE_MS); 
	//gpio_set_level(PIN_NUM_BCKL, 1);
	mcpwm_set_duty(MCPWM_UNIT_0, MCPWM_TIMER_0, 1, st7735_lcd_backlight);

} 


void LCD_Fill(uint16_t xsta,uint16_t ysta,uint16_t xend,uint16_t yend,uint16_t color)
{          
	uint16_t i,j; 
	Address_Set(xsta,ysta,xend-1,yend-1);//设置显示范围	
	for(i=ysta;i<yend;i++)
	{													   	 	
		for(j=xsta;j<xend;j++)
		{
			LCD_WR_DATA(color);
		}
	} 				  	    
}
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

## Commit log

2022-06-15 RX5808-Div
    RX5808-Div
    [RX5808_BUT.PcbDoc, RX5808_BUT.PrjPcb, RX5808_BUT.SchDoc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]
2022-06-27 Gerber
    Gerber
    [RX5808_BUT.GBL, RX5808_BUT.GBO, RX5808_BUT.GBP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]
2022-08-28 composite video(OSD) switch
2022-09-05 update esp32-video
2022-10-22 update: 适配4KHz的无源蜂鸣器
2022-10-25 update: DAC切换改为GPIO19, 蜂鸣器默认低电平
2022-10-25 update: 支持DAC与VIDEO输出并联，抛弃模拟开关
2022-10-25 update: 支持有源或无源蜂鸣器编译
2022-11-06 update: 支持ESP32-D0WDQ6, 增加编译开关
2022-12-24 add fan&osd
    add fan&osd
    [BOM.xlsx, RX5808_TOP.PrjPcb, RX5808_TOP.SchDoc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]
